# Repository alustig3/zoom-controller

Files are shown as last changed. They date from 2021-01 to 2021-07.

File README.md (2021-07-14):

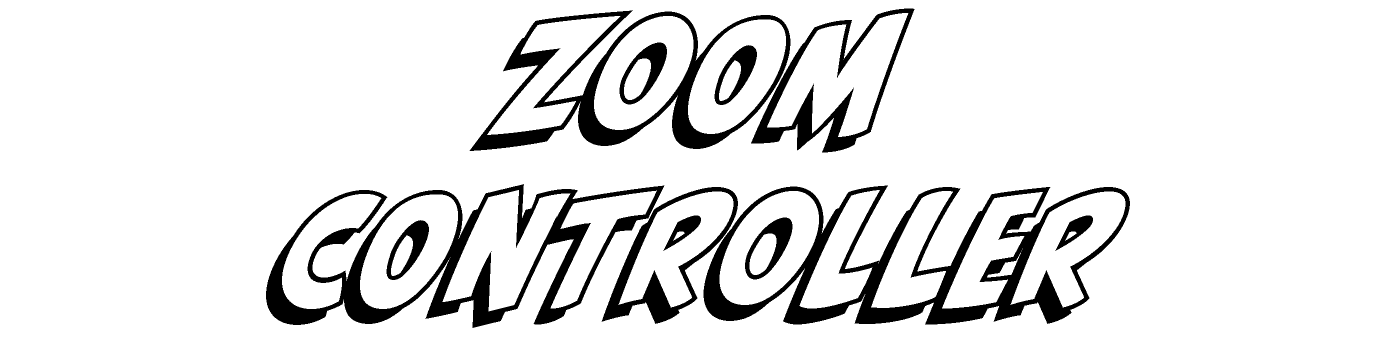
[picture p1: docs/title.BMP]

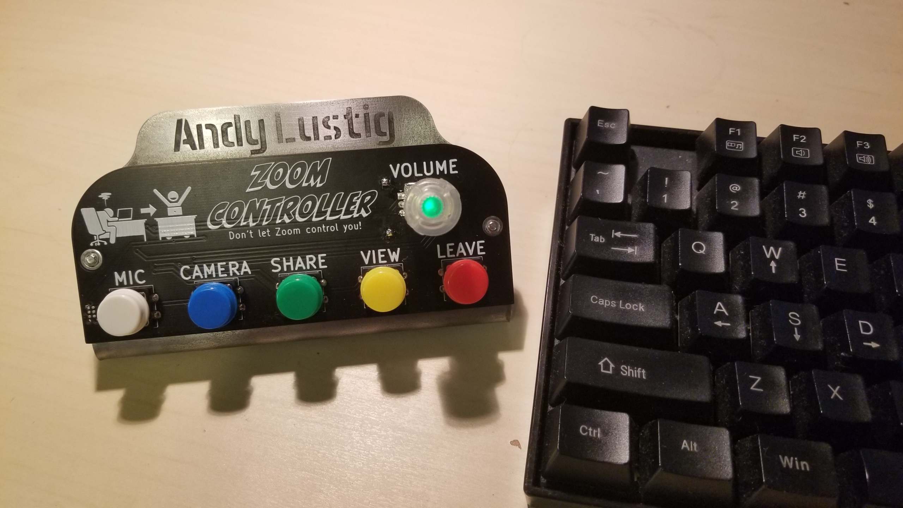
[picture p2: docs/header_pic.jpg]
Zoom Controller

# Table of Contents

- [What is this?](#what-is-this)
  - [Demo Video](#demo-video)
- [How do I use it?](#how-do-i-use-it)
  - [Turning on](#turning-on)
  - [Connecting to Bluetooth](#connecting-to-bluetooth)
  - [Turning off](#turning-off)
  - [Disconnecting Bluetooth](#disconnecting-bluetooth)
  - [Adjust volume](#adjust-volume)
  - [Controlling Zoom!](#controlling-zoom)
  - [Switching modes](#switching-modes)
- [Getting fancy](#getting-fancy)
  - [Desktop notifications](#desktop-notifications)
  - [YouTube controller](#youtube-controller)
- [How do I make one?](#how-do-i-make-one)
  - [Stand](#stand)
  - [Electronics](#electronics)
  - [Additional hardware](#additional-hardware)
  - [Software](#software)
- [Feedback](#feedback)
# What is this?
I, like many others, found myself using Zoom video conference software a lot this past year. 
I created this device to make interacting with Zoom faster and more pleasant. 

- The Zoom Controller connects with your computer over Bluetooth and emulates keyboard key presses
- Works with Mac and Windows
- Five buttons are setup to emulate the default keyboard shortcuts in Zoom
- A knob controls the computer's media volume
- Powered by two AA batteries
- The circuit board mounts to a bent piece of 12 Gauge steel
- Bonus features include desktop notifications and YouTube Mode (see [getting fancy](#getting-fancy))

## Demo video
<div style="">
  <a href="https://alustig3.github.io/zoom-controller/demovideo.mp4">
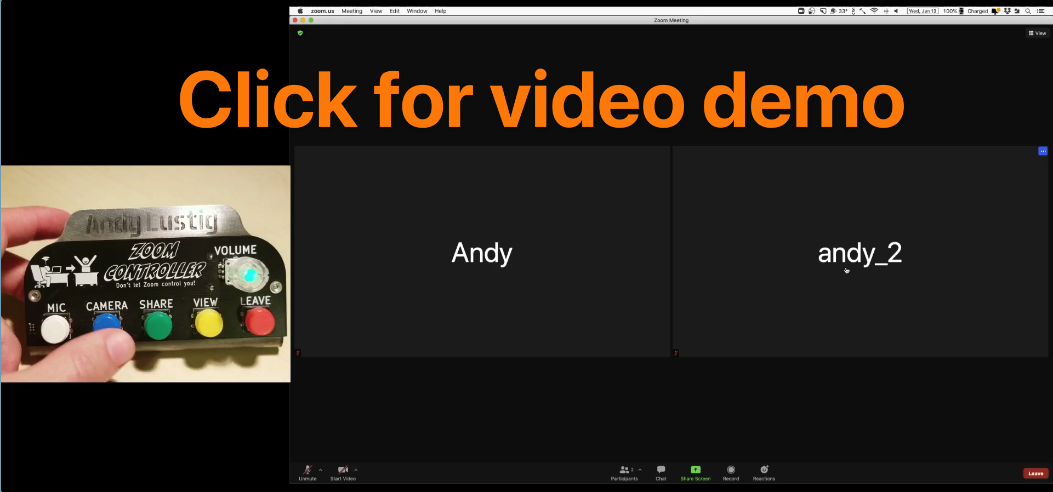
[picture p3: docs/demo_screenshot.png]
  
  </a>
</div>

# How do I use it? 
- [Turning on](#turning-on)
- [Connecting to Bluetooth](#connecting-to-bluetooth)
- [Turning off](#turning-off)
- [Disconnecting Bluetooth](#disconnecting-bluetooth)
- [Controlling Zoom!](#controlling-zoom)
- [Switching modes](#switching-modes)

## Turning on
Press and hold the **VOLUME** knob to turn on. 
You can let go of the knob as soon as you see it light up red. 
The knob will "breathe" red light while it is trying to connect to Bluetooth. Once connected, the knob will turn green. 

The controller will automatically turn off after 20 seconds attempting and failing to connect.

## Connecting to Bluetooth
If it is the first time using Zoom Controller, you will need to add it your computer's list of Bluetooth devices. Once added, the Zoom Controller will automatically connect when turned on and within range of your computer.
### Mac
- Open System Preferences -> Bluetooth
- [Turn on](#turning-on) Zoom Controller
- When it appears in your list of Bluetooth devices, click connect. Once connected, the light will turn green, and you're good to go!
- There may be a "Keyboard Setup Assistant" window that pops up asking you to press a key to identify your keyboard. You can ignore this and just close the window.

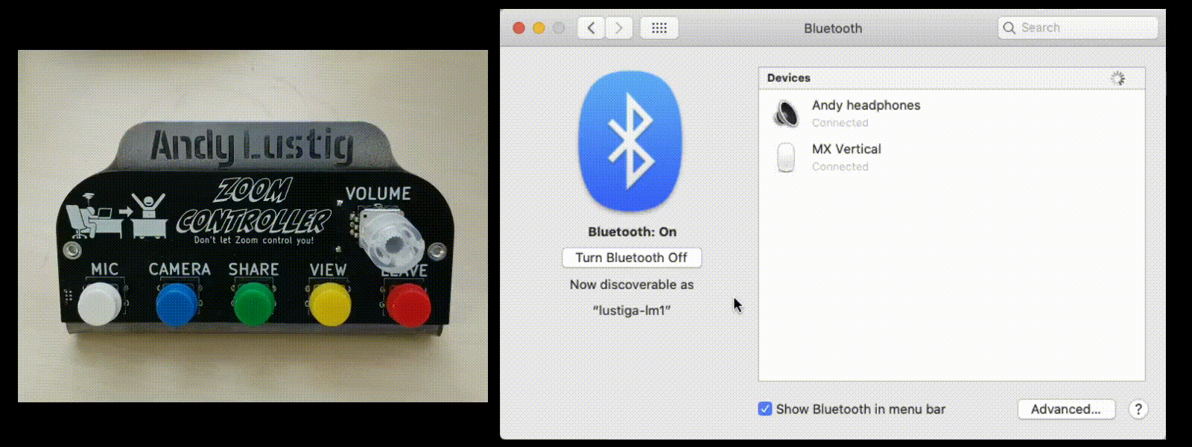
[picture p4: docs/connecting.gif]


### Windows
- Search for "bluetooth" in the search bar and select "Bluetooth and other devices settings"
- At the top, click "Add Bluetooth or other device"
- Click "Bluetooth - Mice, keyboards, pens or other kinds of Bluetooth devices"
- Turn on the Zoom Controller by pressing the **VOLUME** knob until a red light appears
- Zoom controller should appear in the "Add a device" list



## Turning off
Press and hold the **LEAVE** button. The volume knob's light will turn off when the controller is powered off.

There is an idle clock always counting. 
Every time you press a button or rotate the knob, the idle clock is reset to 0. 
If the idle clock reaches 60 minutes, the controller will automatically turn itself off to save battery.

## Disconnecting Bluetooth
The Zoom Controller can only be connected to one device at a time. If you want to use it with a different computer it is important that you first remove it from its current computer's Bluetooth device list.
### Mac
- Open to System Prefrences -> Bluetooth
- Right click on the Zoom Controller and select "Remove"
### Windows
- Search for "bluetooth" in the search bar and select "Bluetooth and other devices settings"
- Under the "Mouse, keyboard, & pen" click "Zoom Controller" and then click "Remove device"

## Controlling Zoom!

### Adjust volume
Rotate the **VOLUME** knob clockwise to increase volume, counterclockwise to decrease volume.

### Send Shortcuts on Mac
The five buttons are setup to execute the following Zoom functions by emulating their default keyboard shortcuts.

| Button | Zoom Function | Emulated Mac Keypress |
|---|---|---|
| Mic | mute/unmute microphone | shift + command + a |
| Camera | start/stop video | shift + command + v |
| Share  | start/stop screen sharing | shift + command + s |
| View | speaker/gallery view | shift + command + w |
| Leave* | leave meeting | command + w, followed by Return to confirm leave |

### Send Shortcuts on Windows

| Button | Zoom Function | Emulated Windows Keypress |
|---|---|---|
| Mic | mute/unmute microphone | alt + a |
| Camera | start/stop video | alt + v |
| Share | start/stop screen sharing | alt + s |
| View (single press) | speaker view | alt + F1 |
| View (double press) | gallery view | alt + F2 |
| Leave* | leave meeting | alt + q, folowed by Enter to confirm leave |

**Zoom Controller will automatically turn off 8 seconds after pressing **LEAVE**, unless you keep it awake by pressing a button or rotating the knob within those 8 seconds. 
The knob will blink green indicating that the controller is about to turn itself off.*

## Switching modes
Keyboard shortcuts sent by Zoom Controller depend on which operating system and which application is being used. 
Because of this, there are 4 different modes that Zoom controller can be in. 
There are 2 operating system modes (Mac, Windows) and 2 application modes (Zoom, YouTube*).

**see [YouTube Controller](#youtube-controller)*

### Mac mode
- Press down the **VOLUME** button. 
- While holding the **VOLUME** button, press and hold the **MIC** button for 2 seconds
- The **VOLUME** button will blink **3** times indicating it is now in Mac mode. You can release both buttons.

### Windows mode
- Press down the **VOLUME** button. 
- While holding the **VOLUME** button, press and hold the **CAMERA** button for 2 seconds
- The **VOLUME** button will blink **7** times indicating it is now in Windows mode. You can release both buttons.

### Switch into Zoom mode
- Press and hold the VOLUME knob
- Press and release the MIC button

### Switch into YouTube mode
- Press and hold the VOLUME knob
- Press and release the CAMERA button

# Getting fancy
## Desktop notifications
You can enable Zoom Controller notifications show up on your desktop. The following notifications will appear when relevant:
- "Mac Mode"
- "Windows Mode"
- "Zoom Mode"
- "YouTube Mode"
- "Controller has been idle for awhile and will soon turn itself off. Press any button or rotate knob to keep awake"
### Mac notifications setup
- Download [Hammerspoon](https://www.hammerspoon.org/).
- Click the Hammerspooon menu bar icon and select "Open Config".
- Add the following to your `init.lua` file:
```lua
hs.hotkey.bind({"cmd", "alt", "ctrl"}, "F1", function()
  hs.alert.show("Mac Mode")
end)

hs.hotkey.bind({"cmd", "alt", "ctrl"}, "F2", function()
  hs.alert.show("Windows Mode")
end)

hs.hotkey.bind({"cmd","alt","ctrl"}, "F3", function()
  hs.notify.new({title="Zoom Controller Idle", informativeText="Controller will turn off soon\nPress any key to keep awake"}):send()
end))

hs.hotkey.bind({"cmd", "alt", "ctrl"}, "F4", function()
  hs.alert.show("Zoom Mode")
end)

hs.hotkey.bind({"cmd", "alt", "ctrl"}, "F5", function()
  hs.alert.show("YouTube Mode")
end)

```
- Save your changes to the `inti.lua` file then click the Hammerspoon menu bar icon and select "Reload Config" 
### Windows notifications setup
- Download [AutoHotkey](https://www.autohotkey.com/)
- Download this [zoom_controller_notifications.ahk](docs/zoom_controller_notifications.ahk) script file
- Once the script file is downloaded, double click it to begin running the script
- If you want the script to automatically run every time you turn on your computer, follow instructions [here](https://www.autohotkey.com/docs/FAQ.htm#Startup)

## YouTube controller
I've found this device to be super useful for watching online videos.

### Installation
- Add an extension called **Video Speed Controller** to your web browser
  - [Chrome extension](https://chrome.google.com/webstore/detail/video-speed-controller/nffaoalbilbmmfgbnbgppjihopabppdk)
  - [Firefrox extension](https://addons.mozilla.org/en-US/firefox/addon/videospeed/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)

### Controlling YouTube
#### Send Shortcuts
| Button | YouTube Function  | Emulated Keypress |
|---|---|---|
| Mic | | |
| Camera | rewind 10s | z |
| Share  | fast forward 10s  | x |
| View | toggle fullscreen | f |
| Leave  | play/pause | spacebar |

#### Adjust playback speed
- Increase/decrease the video playback speed by rotating the VOLUME knob clockwise/counterclockwise
- Toggle between 1X speed and your adjusted playback speed by clicking the VOLUME knob
#### Adjust Volume
- Increase/decrease the volume by pressing and holding down MIC then rotating the VOLUME knob clockwise/counterclockwise.

# How do I make one?
## Stand
- File for lasercutting: [stand.dxf](https://alustig3.github.io/zoom-controller/stand.dxf)
- 0.1" thick (12Ga) steel cut and bent at https://www.oshcut.com/

## Electronics
### Bill of Materials
| Qty | Reference | Description | Value/MPN | 
|-----|---|---|---|
| 1 | BT1 | Battery Holder | [2462](https://www.digikey.com/product-detail/en/keystone-electronics/2466/36-2466-ND/303815) | 
| 1 | C1 | 0805 Capacitor | 10nF | 
| 1 | D1 | Schottky Diode | [BAT54C](http://www.diodes.com/_files/datasheets/ds11005.pdf) | 
| 2 | H3, H4 | Threaded Standoff | [4207](https://www.adafruit.com/product/4207) | 
| 1 | Q1 | P-Channel MOSFET  | [FDN340P](https://www.digikey.com/products/en?keywords=FDN340PCT-ND) | 
| 1 | Q2 | N-Channel MOSFET  | [BSS123](https://www.digikey.com/products/en?keywords=BSS123LT1GOSCT-ND) | 
| 1 | R1 | 0805 Resistor | 100KΩ | 
| 1 | R2 | 0805 Resistor | 10KΩ | 
| 1 | R3 | 0805 Resistor | 330Ω | 
| 1 | R4 | 0805 Resistor | 1MΩ | 
| 5 | S1, S2, S3, S4, S5 | Tactile Button | [DD-15326](https://www.sparkfun.com/products/15326) | 
| 1 | SW1 | Rotary Encoder | [COM-15140](https://www.sparkfun.com/products/15140) | 
| 1 | U1 | Microcontroller | [ESP32-WROOM-32E](https://www.digikey.com/en/products/detail/espressif-systems/ESP32-WROOM-32E-4MB/11613125) | 

<div style="">
  <a href="https://alustig3.github.io/zoom-controller/ibom.html">
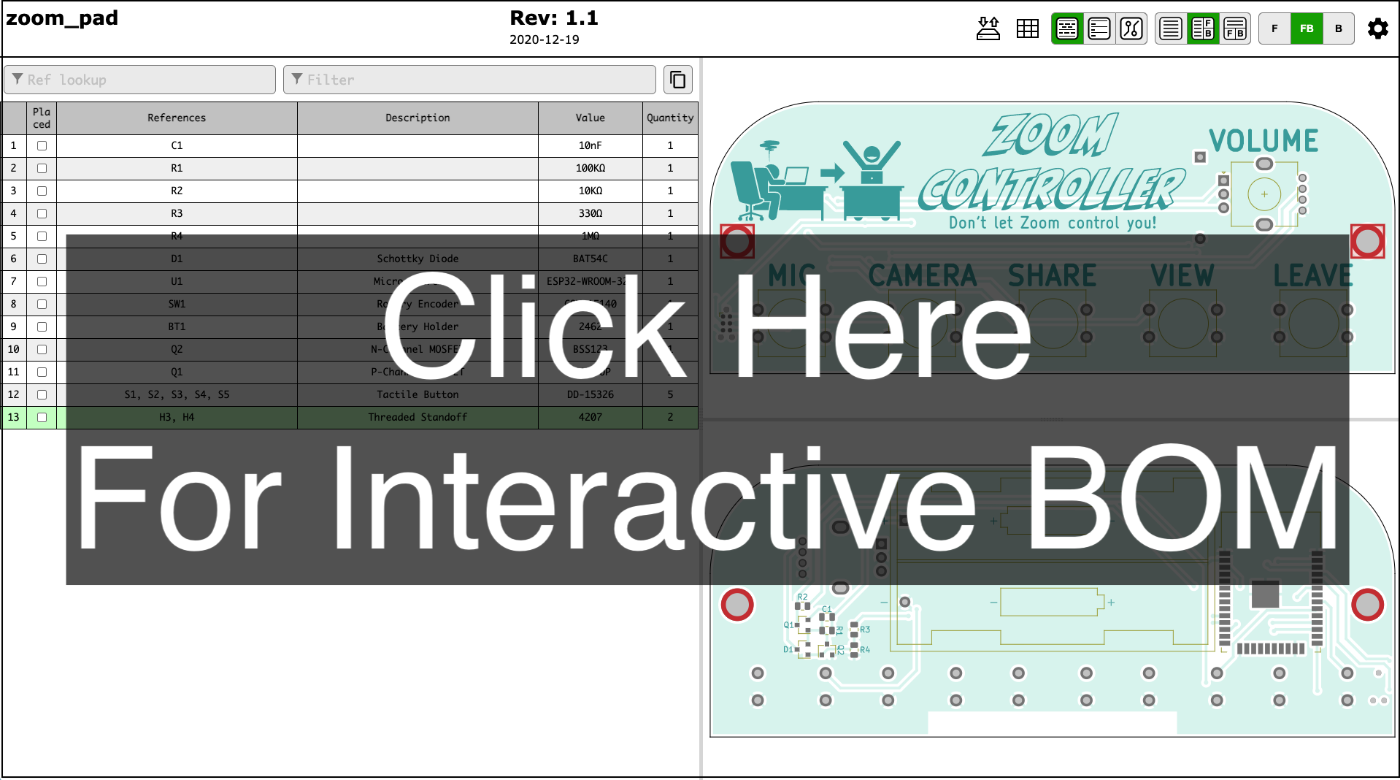
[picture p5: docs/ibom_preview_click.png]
  
  </a>
</div>

## Additional hardware
- 6mm long M3 x 0.5mm screws: https://www.mcmaster.com/92095A179/
- Clear plastic knob for rotary encoder: https://www.sparkfun.com/products/10597

## Software
The code was developed using [PlatformIO](https://docs.platformio.org/en/latest/boards/espressif32/esp32dev.html).
An [ESP-PROG](https://www.digikey.com/en/products/detail/espressif-systems/ESP-PROG/10259352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) was used to program the ESP32 microcontroller.
You should be able to use the platform.ini file from this repository, you'll just need to change the upload port. 
The platform.ini will automatically download the requisite [ESP32-BLE-Keyboard](https://github.com/T-vK/ESP32-BLE-Keyboard) library and ESP32 and Arduino frameworks.
# Feedback
If people are interested, I may consider buying some parts in bulk and selling the controllers on [Tindie](https://www.tindie.com/) or [Etsy](https://www.etsy.com/) ¯\\\_(ツ)_/¯

If you have questions, comments, or are interested in buying a Zoom Controller:

<div style="height:100px;">
  <a href="https://forms.gle/rxcJuvHoePF4XZsw5">
  
  </a>
</div>

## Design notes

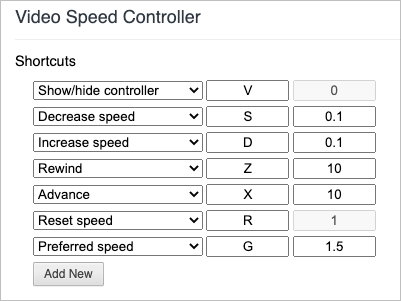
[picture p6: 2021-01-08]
docs/youtube_extension_settings.png

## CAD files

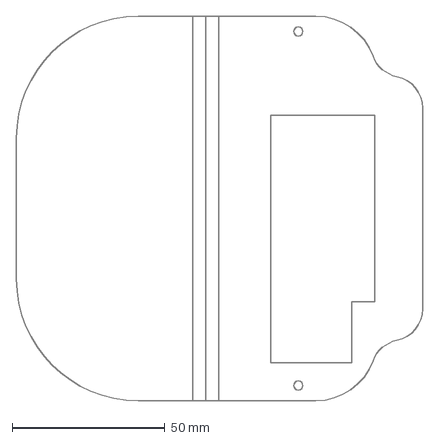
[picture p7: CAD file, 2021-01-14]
docs/stand.dxf
133.1 x 126.0 mm

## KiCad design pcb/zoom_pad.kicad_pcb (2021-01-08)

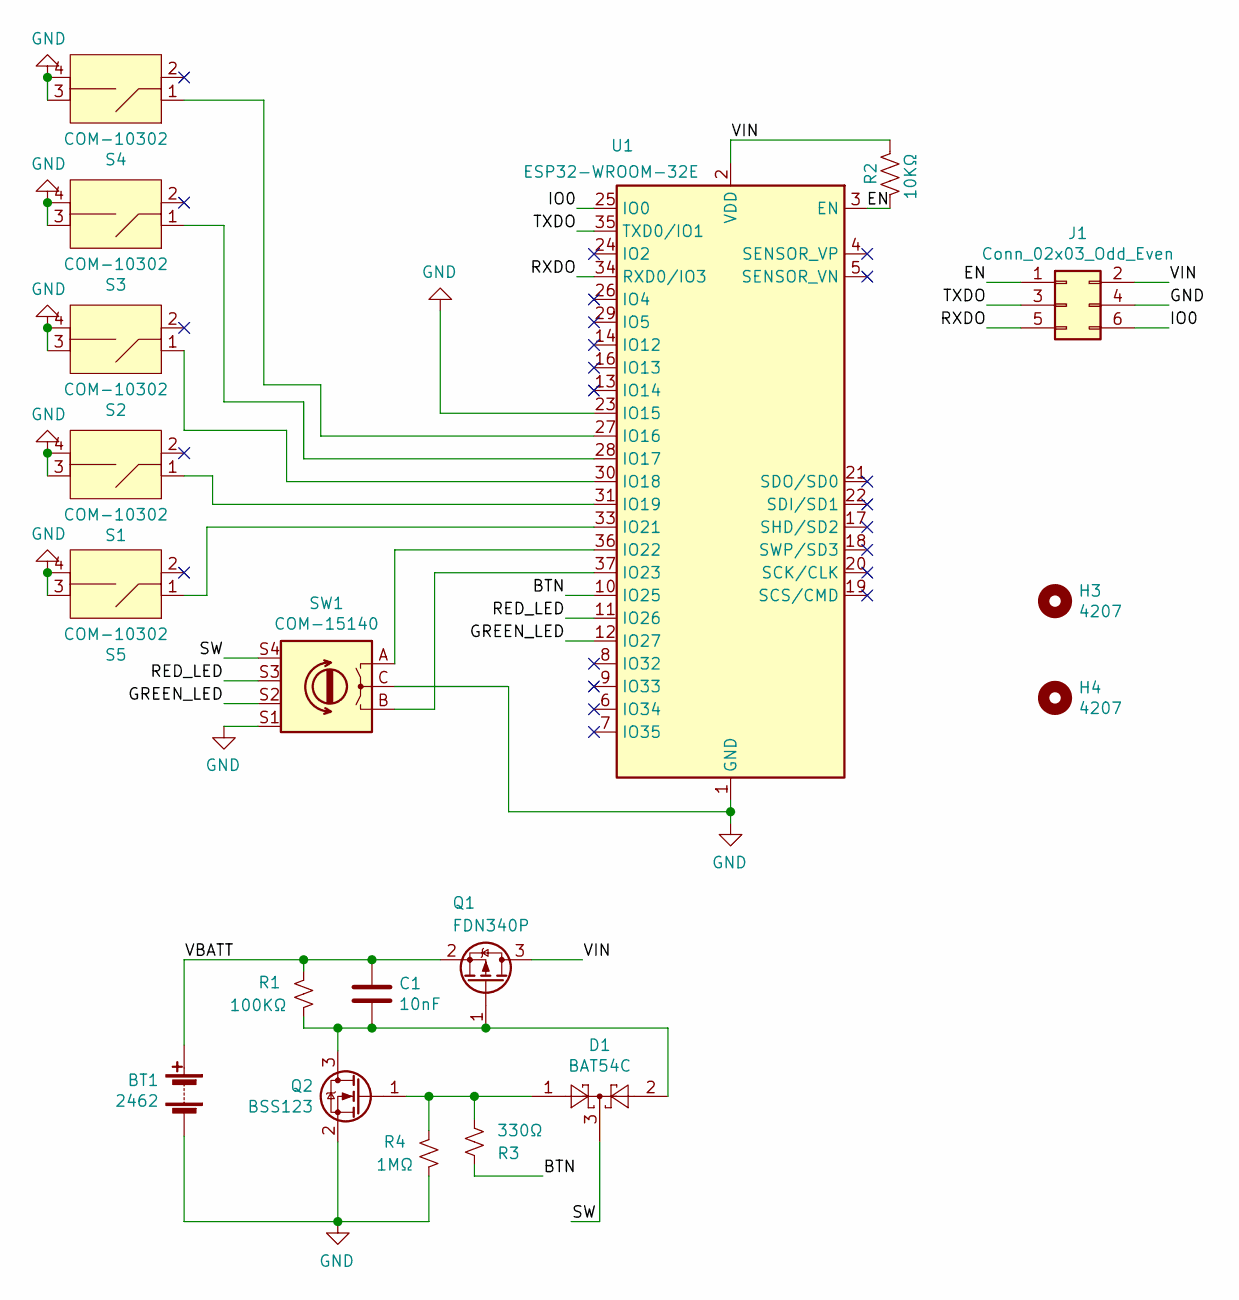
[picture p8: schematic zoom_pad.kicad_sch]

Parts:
BT1: 2462; BatteryHolder_Keystone_2462_2xAA
C1: 10nF; C_0805_2012Metric
D1: BAT54C; SOT-23; LCSC C397610
H3, H4: 4207; standoff_nut
J1: Conn_02x03_Odd_Even; Tag-Connect_TC2030-IDC-NL_2x03_P1.27mm_Vertical
Q1: FDN340P; SOT-23; LCSC C75469
Q2: BSS123; SOT-23; LCSC C431506
R1: 100KΩ; R_0805_2012Metric
R2: 10KΩ; R_0805_2012Metric
R3: 330Ω; R_0805_2012Metric
R4: 1MΩ; R_0805_2012Metric
S1, S2, S3, S4, S5: COM-10302; sparkfun_tactile_color
SW1: COM-15140; RG_Encoder
U1: ESP32-WROOM-32E; ESP32-WROOM-32; LCSC C701341

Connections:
/BTN: R3.1, U1.10 (IO25)
/EN: J1.1, R2.1, U1.3 (EN)
/GREEN_LED: SW1.S2, U1.12 (IO27)
/IO0: J1.6, U1.25 (IO0)
/RED_LED: SW1.S3, U1.11 (IO26)
/RXDO: J1.5, U1.34 (RXD0/IO3)
/SW: D1.3, SW1.S4
/TXDO: J1.3, U1.35 (TXD0/IO1)
/VBATT: BT1.1 (+), C1.1, Q1.2 (S), R1.2
/VIN: J1.2, Q1.3 (D), R2.2, U1.2 (VDD)
GND: BT1.2 (-), J1.4, Q2.2 (S), R4.1, S1.3 (out1), S1.4 (out2), S2.3 (out1), S2.4 (out2), S3.3 (out1), S3.4 (out2), S4.3 (out1), S4.4 (out2), S5.3 (out1), S5.4 (out2), SW1.C, SW1.S1, U1.1 (GND), U1.15 (GND), U1.23 (IO15), U1.38 (GND), U1.39 (GND)
unnamed: C1.2, D1.2, Q1.1 (G), Q2.3 (D), R1.1
unnamed: D1.1, Q2.1 (G), R3.2, R4.2
unnamed: S1.1 (in1), U1.31 (IO19)
unnamed: S2.1 (in1), U1.30 (IO18)
unnamed: S3.1 (in1), U1.28 (IO17)
unnamed: S4.1 (in1), U1.27 (IO16)
unnamed: S5.1 (in1), U1.33 (IO21)
unnamed: SW1.A, U1.36 (IO22)
unnamed: SW1.B, U1.37 (IO23)

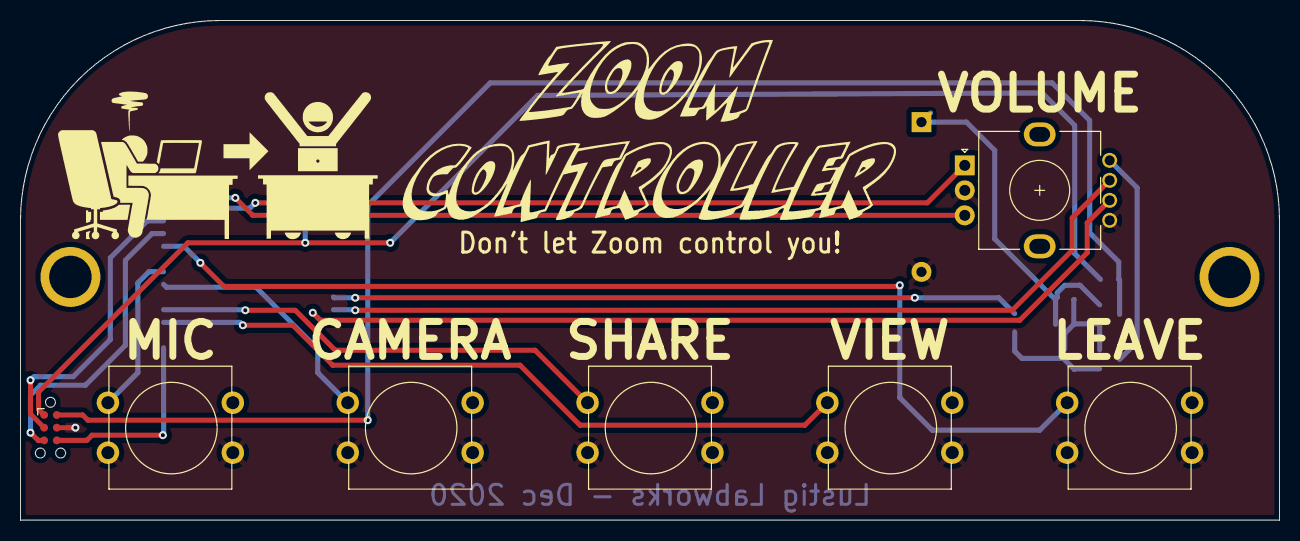
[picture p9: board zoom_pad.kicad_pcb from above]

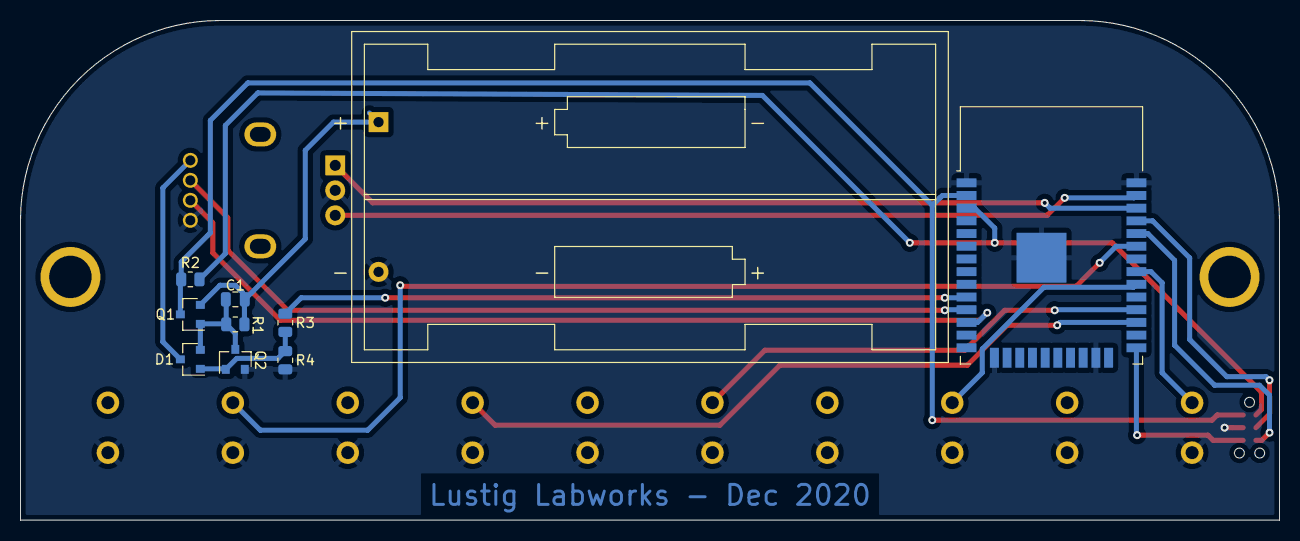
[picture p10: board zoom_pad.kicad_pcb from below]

Board: 2 copper layers, 126.0 x 50.0 mm, 19 parts (10 on the bottom side), 20 nets.

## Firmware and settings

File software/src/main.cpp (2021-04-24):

# define VERSION 2021042300

#include <Arduino.h>
#include <BleKeyboard.h>
#include <EEPROM.h>
#include "soc/soc.h"
#include "soc/rtc_cntl_reg.h"

#define OS_BYTE 0
#define MODE_BYTE 1

BleKeyboard bleKeyboard("Zoom Controller","Lustig Labs");

//timing
unsigned long last_active;
unsigned long idle_limit;
const int connection_timer = 30*1000; // shutdown and stop trying to connect after  25 seconds
const int warning_countdown = 5*1000; // send warning 5 seconds before idle shutdown
const int zoom_idle = 30 * 60*1000; //30 minutes
const int youtube_idle = 5 * 60*1000; //5 minutes
const byte debounce = 200;
const int os_hold = 2000;
const int shutdown_hold = 500;

enum os {mac,windows};
enum os active_os;
enum mode {zoom, youtube};
enum mode active_mode;
enum view {speaker,gallery};

void change_mode(mode newmode);
void change_os(os new_os);
void last_chance(int last_chance_timer);
void reset_inactive_clock();

#include "hardware.h"
#include "bluetooth.h"

///////////////////////////////////////////////////////////////////////////////////////////////////////////////////////////
///////////////////////////////////////////////////////////////////////////////////////////////////////////////////////////
void setup() {
  pinMode(latch_BTN, INPUT_PULLUP);

  WRITE_PERI_REG(RTC_CNTL_BROWN_OUT_REG, 0); //disable brownout detector   

  EEPROM.begin(2); 
  active_mode = static_cast<mode>(EEPROM.read(MODE_BYTE));
  if (active_mode != zoom && active_mode != youtube){
    active_mode = zoom;
  }
  active_os = static_cast<os>(EEPROM.read(OS_BYTE));
  if (active_os != mac && active_os != windows){
    active_os = mac;
  }
  
  ledcSetup(redPWM, freq, resolution);
  ledcWrite(redPWM,knob_brightness);
  ledcSetup(greenPWM, freq, resolution);
  ledcAttachPin(red_LED, redPWM);
  ledcAttachPin(green_LED, greenPWM);
  pinMode(btn_1,INPUT_PULLUP);
  pinMode(btn_2,INPUT_PULLUP);
  pinMode(btn_3,INPUT_PULLUP);
  pinMode(btn_4,INPUT_PULLUP);
  pinMode(btn_5,INPUT_PULLUP);

  bleKeyboard.begin();
  connecting();

  //encoder setup
  pinMode(encoderPin1, INPUT_PULLUP);
  pinMode(encoderPin2, INPUT_PULLUP);
  attachInterrupt(digitalPinToInterrupt(encoderPin1), updateEncoder, CHANGE);
  attachInterrupt(digitalPinToInterrupt(encoderPin2), updateEncoder, CHANGE);

  Serial.begin(115200);

  check_for_hold(latch_BTN,5000,print_version);
  while(!digitalRead(latch_BTN)){
    delay(1);
  }
  delay(debounce);
  reset_inactive_clock();
  change_mode(active_mode);
}

///////////////////////////////////////////////////////////////////////////////////////////////////////////////////////////
void loop() {
  while(!bleKeyboard.isConnected()){
    connecting();
  }
  /***************** ZOOM MODE ********************************/
  if( active_mode == zoom){
    if (tempNow-tempOld>knob_sensitivity){
      bleKeyboard.write(KEY_MEDIA_VOLUME_UP);
      tempNow = tempOld;
      reset_inactive_clock();
    }
    else if (tempNow-tempOld<-knob_sensitivity){
      bleKeyboard.write(KEY_MEDIA_VOLUME_DOWN);
      tempNow = tempOld;
      reset_inactive_clock();
    }
    else if (!digitalRead(latch_BTN)){
      while(!digitalRead(latch_BTN)){
        if(!digitalRead(btn_1)){
          bool was_held = check_for_hold(btn_1, os_hold, change_os,mac);
          if(!was_held){
            change_mode(zoom);
          }
        }
        else if(!digitalRead(btn_2)){
          bool was_held = check_for_hold(btn_2, os_hold, change_os,windows);
          if(!was_held){
            change_mode(youtube);
          }
        }
      }
      reset_inactive_clock();
    }
    else if (!digitalRead(btn_1)){
      shortcut('a'); //toggle mic
      reset_inactive_clock();
    }
    else if (!digitalRead(btn_2)){
      reset_inactive_clock();
      shortcut('v');//toggle video
    }
    else if (!digitalRead(btn_3)){
      shortcut('s'); //share screen
      reset_inactive_clock();
    }
    else if (!digitalRead(btn_4)){
      reset_inactive_clock();
      if(double_click(btn_4)){
        change_view(gallery);
      }
      else{
        change_view(speaker);
      }
      delay(debounce);
    }
    else if (!digitalRead(btn_5)){
      reset_inactive_clock();
      check_for_hold(btn_5, shutdown_hold, shutdown);
      leave(); 
    }
  }
  /***************** YOUTUBE MODE ********************************/
  else if (active_mode == youtube){
    if (tempNow-tempOld>knob_sensitivity){//CW
      bleKeyboard.write('d');
      tempNow = tempOld;
      reset_inactive_clock();
    }
    else if (tempNow-tempOld<-knob_sensitivity){//CCW
      bleKeyboard.write('s');
      tempNow = tempOld;
      reset_inactive_clock();
    }
    else if (!digitalRead(latch_BTN)){
      bool alternate_cmd = false;
      while(!digitalRead(latch_BTN)){
        if(!digitalRead(btn_1)){
          bool was_held = check_for_hold(btn_1, os_hold, change_os,mac);
          if(!was_held){
            change_mode(zoom);
          }
          alternate_cmd = true;
        }
        else if(!digitalRead(btn_2)){
          bool was_held = check_for_hold(btn_2, os_hold, change_os,windows);
          if(!was_held){
            change_mode(youtube);
          }
          alternate_cmd = true;
        }
      }
      if (!alternate_cmd){ //just clicked, did not click and rotate
          bleKeyboard.write('r');
          delay(debounce);
      }
      reset_inactive_clock();
    }
    else if (!digitalRead(btn_1)){
      while(!digitalRead(btn_1)){
        if (tempNow-tempOld>knob_sensitivity){//CW
          tempNow = tempOld;
          bleKeyboard.write(KEY_MEDIA_VOLUME_UP);
        }
        else if (tempNow-tempOld<-knob_sensitivity){//CCW
          tempNow = tempOld;
          bleKeyboard.write(KEY_MEDIA_VOLUME_DOWN);
        }
      }
      reset_inactive_clock();
    }
    else if (!digitalRead(btn_2)){
      bleKeyboard.write('z'); //seek backward
      pulse();
      delay(debounce);
      reset_inactive_clock();
    }
    else if (!digitalRead(btn_3)){
      bleKeyboard.write('x'); //seek forward
      pulse();
      delay(debounce);
      reset_inactive_clock();
    }
    else if (!digitalRead(btn_4)){
      bleKeyboard.write('f'); //toggle fullscreen
      pulse();
      delay(debounce);
      reset_inactive_clock();
    }

    else if (!digitalRead(btn_5)){
      check_for_hold(btn_5, shutdown_hold, shutdown);
      bleKeyboard.write(' '); //play/pause video
      pulse();
      delay(debounce);
      reset_inactive_clock();
    }
  }

  if (millis() - last_active > (idle_limit - warning_countdown)){
    notify(KEY_F3);//send warning
    last_chance(warning_countdown);
    reset_inactive_clock();
  }
}

////////////////////////////////////////////////////////////////////////////////////////////////////////////
////////////////////////////////////////////////////////////////////////////////////////////////////////////
void reset_inactive_clock(){
  last_active = millis();
}

void change_mode(mode newmode){
  switch (newmode){
    case zoom:
      notify(KEY_F4); 
      idle_limit = zoom_idle;
      break;
    case youtube:
      notify(KEY_F5); 
      idle_limit = youtube_idle;
      break;
  }
  pulse();
  active_mode = newmode;
}

void change_os(os new_os){
  if (new_os == windows){
    active_os = windows;
    notify(KEY_F2);
    blink_yellow(7);
  }
  else if (new_os == mac){
    active_os = mac;
    notify(KEY_F1);
    blink_yellow(3);
  }
}

void last_chance(int last_chance_timer){
  unsigned long start_last_chance = millis();
  int blink_delay = 150;
  bool stay_awake = false;
  while( millis() - start_last_chance < last_chance_timer){
    for( int i = 0 ; i<blink_delay; i++){
      ledcWrite(greenPWM,0);
      if(check_for_activity()){
        stay_awake = true;
        start_last_chance = millis() - last_chance_timer;
      }
      else if (!digitalRead(btn_5)){ //press leave button to skip warning and proceed with shutdown
        shutdown();
      }
      delay(1);
    }
    for( int i = 0 ; i<blink_delay; i++){
      ledcWrite(greenPWM,255);
      if(check_for_activity()){
        stay_awake = true;
        start_last_chance = millis() - last_chance_timer;
      }
      else if (!digitalRead(btn_5)){ //press leave button to skip warning and proceed with shutdown
        shutdown();
      }
      delay(1);
    }
  }
  if(stay_awake){
    ledcWrite(greenPWM,knob_brightness);
    delay(debounce);
  }
  else{ // there was no activity during warning, so we continue with shutdown
    shutdown();
  }
}

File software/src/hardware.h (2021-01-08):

// pin defines
const byte latch_BTN = 25;
const byte encoderPin1 = 22;
const byte encoderPin2 = 23;
const byte btn_1 = 19;
const byte btn_2 = 18;
const byte btn_3 = 17;
const byte btn_4 = 16;
const byte btn_5 = 21;
const byte red_LED = 26;
const byte green_LED = 27;

//knob
volatile int lastEncoded = 0;
int tempNow = 0,tempOld = 0;
const byte knob_sensitivity = 2;
const byte resolution = 8;
const byte redPWM = 0;
const byte greenPWM = 1;
const int freq = 500; // 5000 Khz produced a hum at 50% duty cycle, so brought this down
const byte knob_brightness = 100;


//hardware
void updateEncoder();
bool check_for_activity();
bool double_click( int btn_pin);
bool check_for_hold(int btn_pin, int hold_duration, void (*passed_fxn)());
bool check_for_hold(int btn_pin, int hold_duration, void (*passed_fxn)(os),os newos);
void blink_yellow(int num_blinks);
void pulse();


void updateEncoder(){
  int MSB = digitalRead(encoderPin1); //MSB = most significant bit
  int LSB = digitalRead(encoderPin2); //LSB = least significant bit
  int encoded = (MSB << 1) |LSB; //converting the 2 pin value to single number
  int sum  = (lastEncoded << 2) | encoded; //adding it to the previous encoded value
  if(sum == 0b1101 || sum == 0b0100 || sum == 0b0010 || sum == 0b1011) tempNow++;
  if(sum == 0b1110 || sum == 0b0111 || sum == 0b0001 || sum == 0b1000) tempNow--;
  lastEncoded = encoded; //store this value for next time
}

bool check_for_activity(){
  if (tempNow-tempOld>knob_sensitivity){
    return true;
  }
  if (tempNow-tempOld<-knob_sensitivity){
    return true;
  }
  if (!digitalRead(latch_BTN)){//
    return true;
  }
  if (!digitalRead(btn_1)){//
    return true;
  }
  if (!digitalRead(btn_2)){//
    return true;
  }
  if (!digitalRead(btn_3)){//
    return true;
  }
  if (!digitalRead(btn_4)){//
    return true;
  }
  return false;
}

bool double_click(int btn_pin){
  while(!digitalRead(btn_pin)){
    delay(2); //in first press
  }
  int second_press_timer = 0;
  bool double_clicked = false;
  while(second_press_timer < 120){
    delay(1);
    second_press_timer++;
    if (!digitalRead(btn_pin)){
      Serial.println("Double click!");
      double_clicked = true;
      break;
    }
  }
  Serial.println(second_press_timer);
  return double_clicked;
}

bool check_for_hold(int btn_pin, int hold_duration, void (*passed_fxn)()){
    int hold_count = 0;
    bool hold_threshold_met = false;
    while(!digitalRead(btn_pin)){
      delay(1);
      hold_count++;
      if (hold_count>hold_duration){
        passed_fxn();
        while(!digitalRead(btn_pin)){
          delay(1);
        }
        hold_threshold_met = true;
      }
    }
    return hold_threshold_met;
}

bool check_for_hold(int btn_pin, int hold_duration, void (*passed_fxn)(os),os newos){
    int hold_count = 0;
    bool hold_threshold_met = false;
    while(!digitalRead(btn_pin)){
      delay(1);
      hold_count++;
      if (hold_count>hold_duration){
        passed_fxn(newos);
        while(!digitalRead(btn_pin)){
          delay(1);
        }
        hold_threshold_met = true;
      }
    }
    return hold_threshold_met;
}

void blink_yellow(int num_blinks){
  for (int i=0; i<num_blinks;i++){
    ledcWrite(greenPWM,0);
    delay(250);
    ledcWrite(greenPWM,knob_brightness);
    delay(250);
  }
}

void pulse(){
  for (int i = 255; i >knob_brightness; i--){
    ledcWrite(greenPWM,i);
    delay(1);
  }
}

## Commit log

2021-01-08 make files public
    [zoom_pad.kicad_pcb, zoom_pad.kicad_sch]
2021-01-14 Doc update
    - added gif for connecting to bluetooth on windows
    - added download link for stand.dxf
    [stand.dxf]
2021-01-28 shutdown warning updates
    - shortened blinking warning period to 5s
    - can skip warning period and immediately shutdown by pressing "leave" button
    [main.cpp]
